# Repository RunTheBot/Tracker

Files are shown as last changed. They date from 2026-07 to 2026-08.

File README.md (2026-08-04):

# Mesh Tracker
A Mesh Tracker based on Meshtastic, in the form of a compass!

Assembly 1



## Features
- LCD For graphics
- Battery and Built-In Charger
- 9 Axis IMU (6 Axis + Magnometer)
- BLE, WiFi, LoRA
- Nearby Pairing

## How it works
Uses LoRa to transmit to the Meshtastic network on a private channel.

## Links
[CAD](https://cad.onshape.com/documents/e3691873ac5a479e26355872/w/654b772ea547b2e6e45daab3/e/722a3034d5cb82f9e90410ab)
[Firmware](https://github.com/runthebot/meshtastic)
[PCB](https://github.com/RunTheBot/Tracker/tree/main/PCB/tracker)
[BOM](https://docs.google.com/spreadsheets/d/1oAZxLPN-XNKiKrUyTvPvqBS-V4H7fdXqoOiTHCyojNU/edit?usp=sharing)

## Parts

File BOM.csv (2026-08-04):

Column 1 | Qty | Price Per | Toral | URL
100mW 0Ω Thick Film Resistor -100ppm/℃~+600ppm/℃ 0402 Chip Resistor - Surface Mount RoHS | 100 |  | 0.45 | https://www.lcsc.com/product-detail/C242160.html
100nF ±10% 50V Ceramic Capacitor X7R 0603 | 50 |  | 1.14 | https://www.lcsc.com/product-detail/C14663.html
10kΩ ±1% 100mW 0603 Thick Film Resistor | 100 |  | 0.38 | https://www.lcsc.com/product-detail/C2906982.html
10uF ±20% 25V Ceramic Capacitor X5R 0603 | 20 |  | 1.66 | https://www.lcsc.com/product-detail/C96446.html
2kΩ ±1% 100mW 0603 Thick Film Resistor | 100 |  | 0.91 | https://www.lcsc.com/product-detail/C22975.html
Connector Receptacle IPEX Male Pin 50Ω Surface Mount | 5 |  | 0.51 | https://www.lcsc.com/product-detail/C88374.html
100mW 4.7kΩ 75V Thick Film Resistor ±100ppm/℃ ±1% 0603 Chip Resistor - Surface Mount RoHS | 100 |  | 0.57 | https://www.lcsc.com/product-detail/C99782.html
4.7uF ±10% 16V Ceramic Capacitor X5R 0603 | 20 |  | 0.67 | https://www.lcsc.com/product-detail/C19666.html
5.1kΩ ±1% 100mW 0603 Thick Film Resistor | 100 |  | 0.27 | https://www.lcsc.com/product-detail/C2907044.html
3.3V Positive Fixed SOT-23-5 Voltage Regulators - Linear, Low Drop Out (LDO) Regulators RoHS | 5 |  | 0.55 | https://www.lcsc.com/product-detail/C23380830.html
Connector Header 2 position 2mm Pitch 2A Right Angle -25℃~+85℃ | 20 |  | 0.79 | https://www.lcsc.com/product-detail/C173752.html
Diode Independent 40V 1A Surface Mount SOD-123FL | 50 |  | 0.73 | https://www.lcsc.com/product-detail/C2909920.html
LGA-14(2.5x3) IMUs (Inertial Measurement Units) RoHS | 3 |  | 13.09 | https://www.lcsc.com/product-detail/C22461202.html
LCC-18(9.7x10.1) RF Receivers RoHS | 3 |  | 32.04 | https://www.lcsc.com/product-detail/C4153167.html
3.75V~6V 1 Lithium Battery 500mA SOT-23-5 Battery Chargers RoHS | 3 |  | 2.96 | https://www.lcsc.com/product-detail/C144308.html
30V 4A Surface Mount SOT-23 | 5 |  | 0.5 | https://www.lcsc.com/product-detail/C15127.html
LGA-16(3x3) Linear, Compass (ICs) RoHS | 3 |  | 4.69 | https://www.lcsc.com/product-detail/C2847467.html
Tactile Switch SPST 2mm 3.9mm x 2.93mm Surface Mount | 10 |  | 0.6 | https://www.lcsc.com/product-detail/C455280.html
USB-C (USB TYPE-C) Receptacle Connector 16 Position Surface Mount, Right Angle | 5 |  | 0.42 | https://www.lcsc.com/product-detail/C2988369.html
Wio-S3 Wireless Module Hand Solder | 3 |  | 23.97 | https://www.seeedstudio.com/Wio-S3-Wireless-Module-p-6832.html
PinSocket_1x07_P2.54mm_Vertical | 1 | 3.15 | 3.15 | https://www.aliexpress.com/item/1005006733621288.html?mp=1
Display | 3 | 6.36 | 19.08 | https://www.aliexpress.com/item/1005008848200231.html
Seeed Shipping |  |  | 17.68
LCSC Shipping |  |  | 12.67

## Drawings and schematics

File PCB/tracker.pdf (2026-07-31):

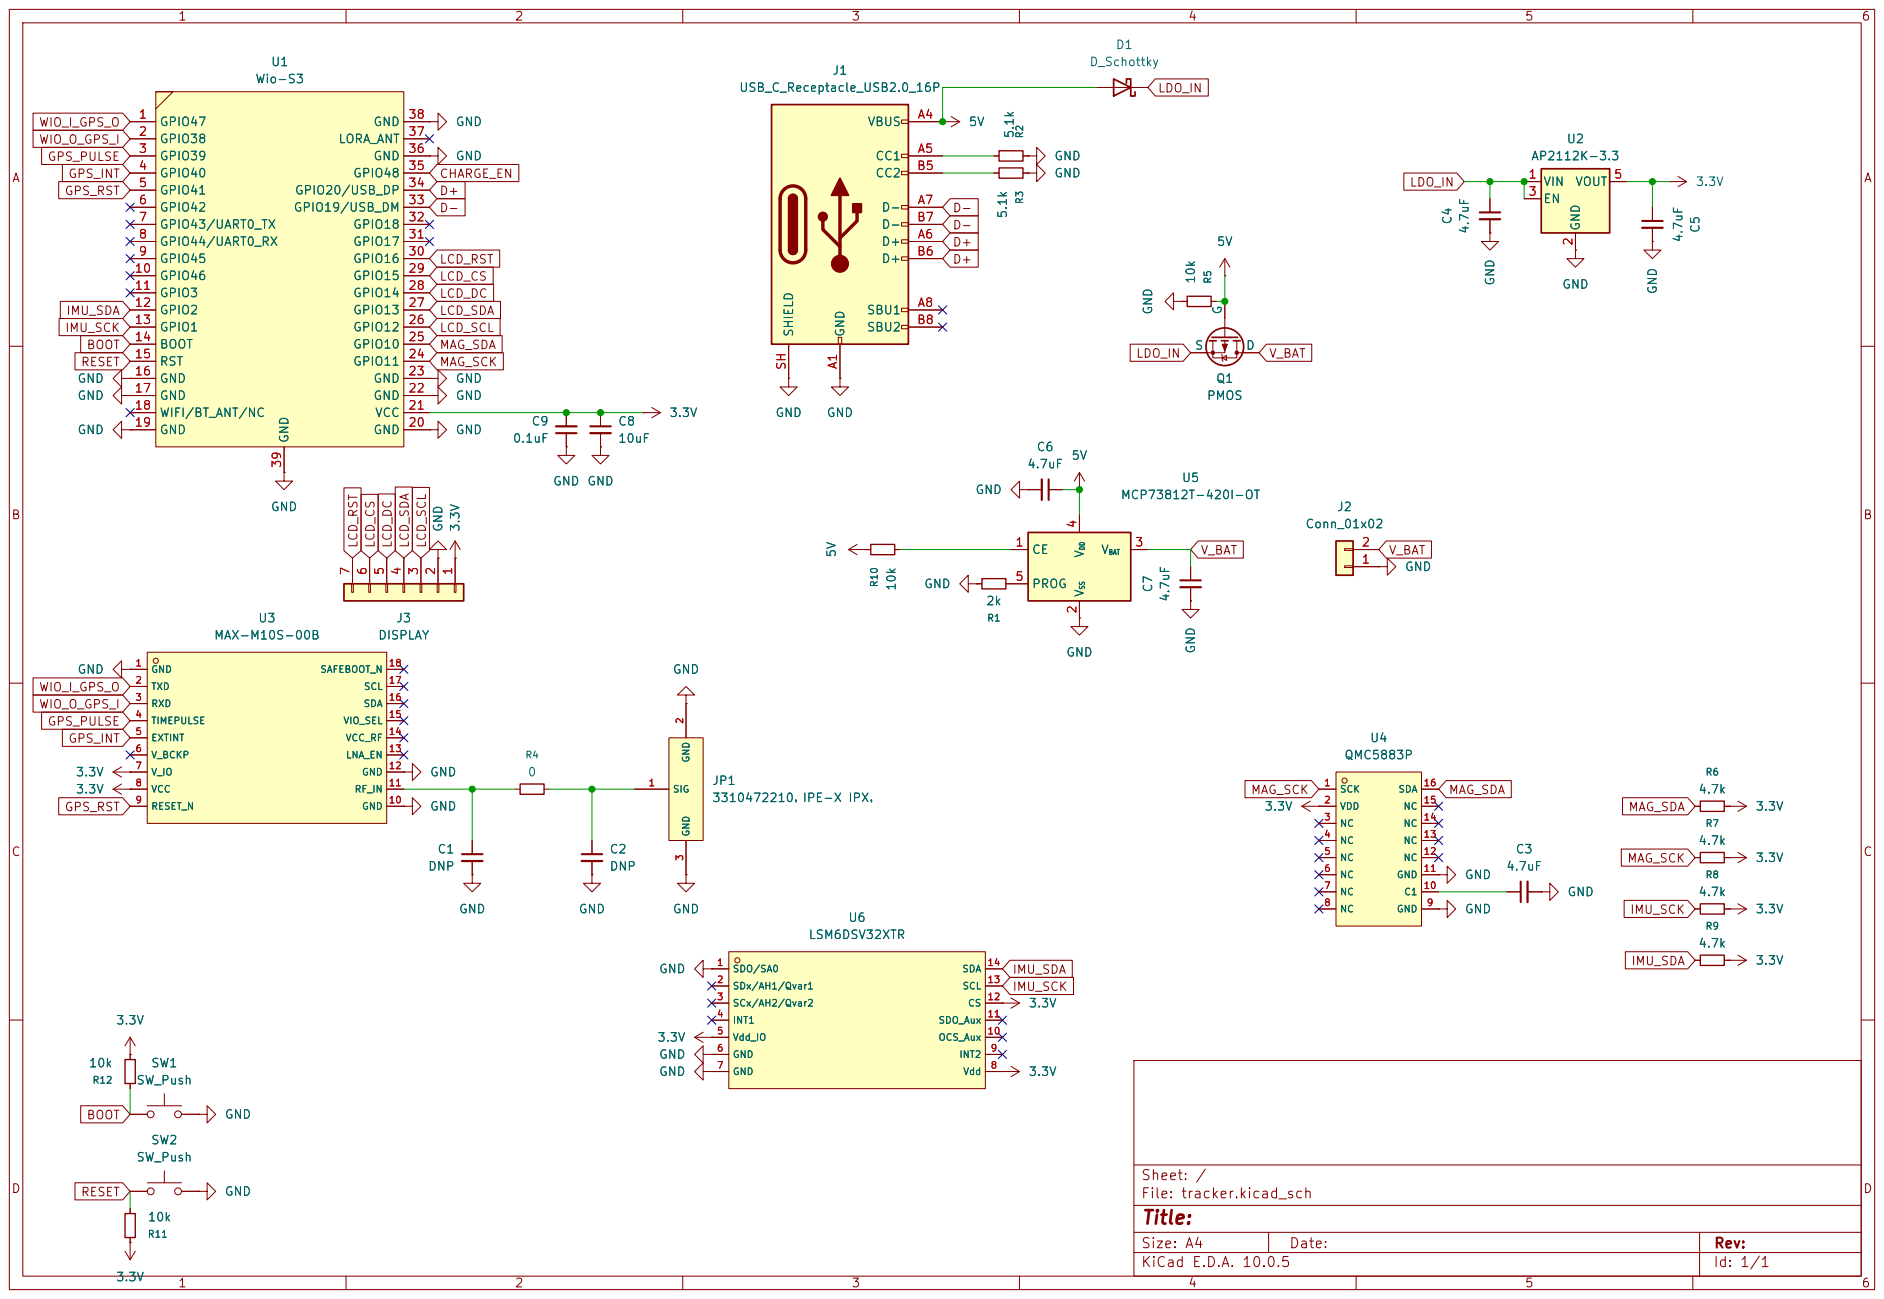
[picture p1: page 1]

VDD 4 PROG 5 GND C7 4.7uF GND GND C5 4.7uF Q1 PMOS D

VDD 4 PROG 5 U5 MCP73812T-420I-OT GND

Size: A4 | Rev:
KiCad E.D.A. 10.0.5 | Id: 1/1

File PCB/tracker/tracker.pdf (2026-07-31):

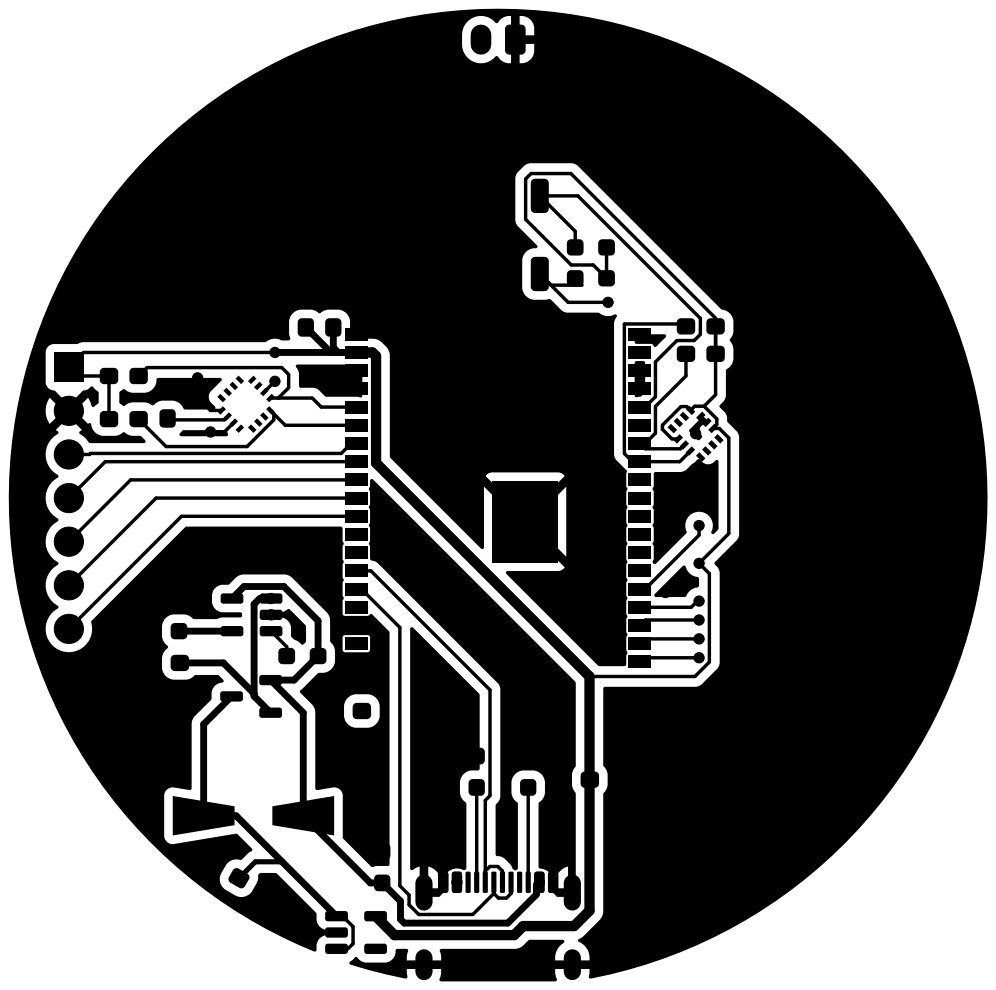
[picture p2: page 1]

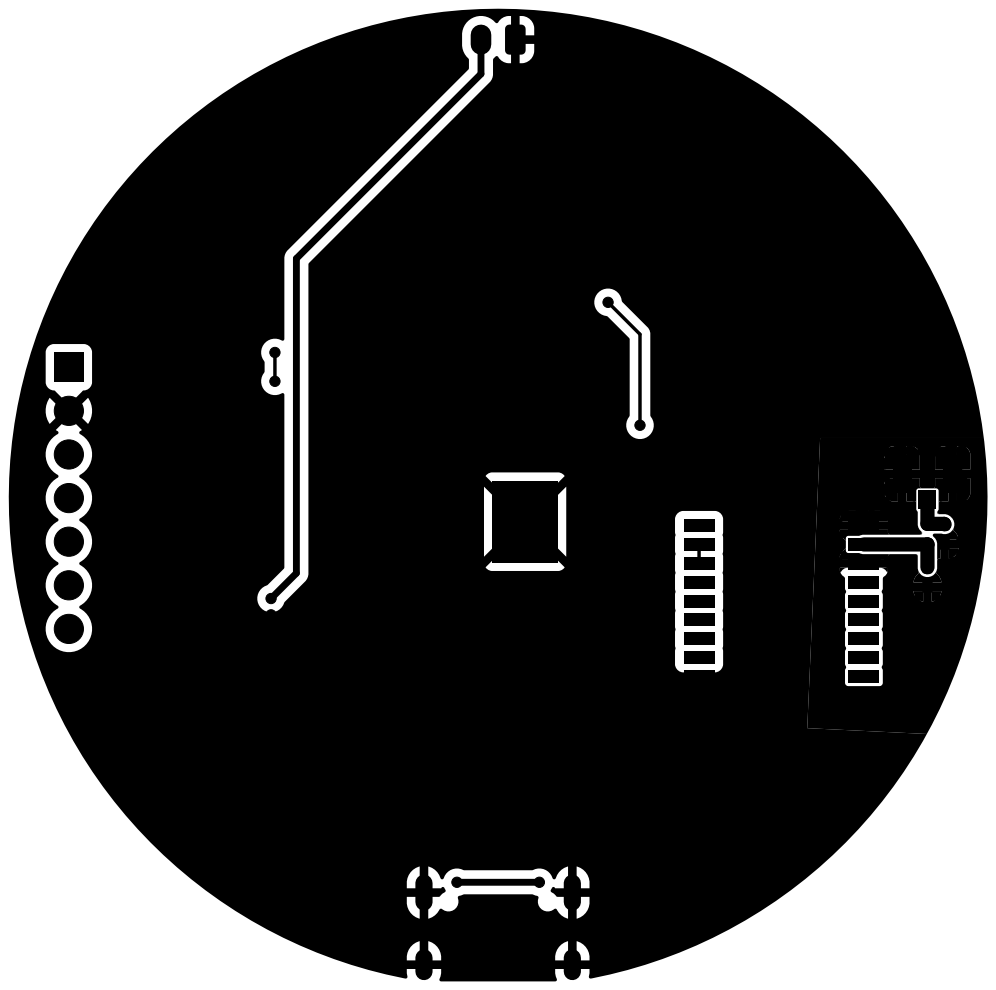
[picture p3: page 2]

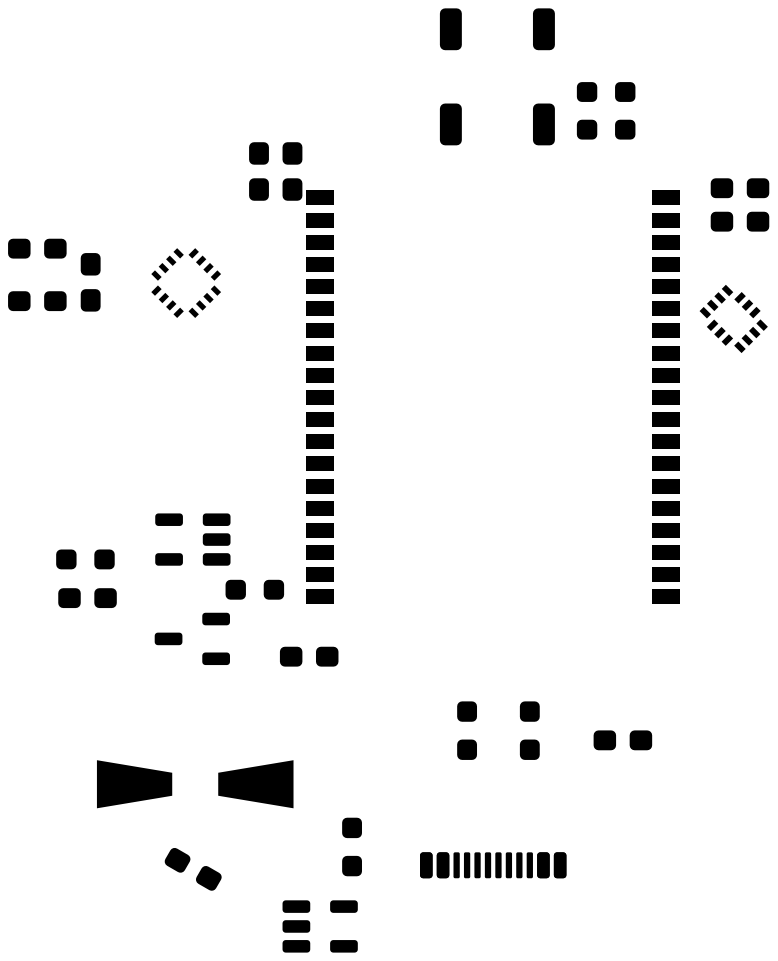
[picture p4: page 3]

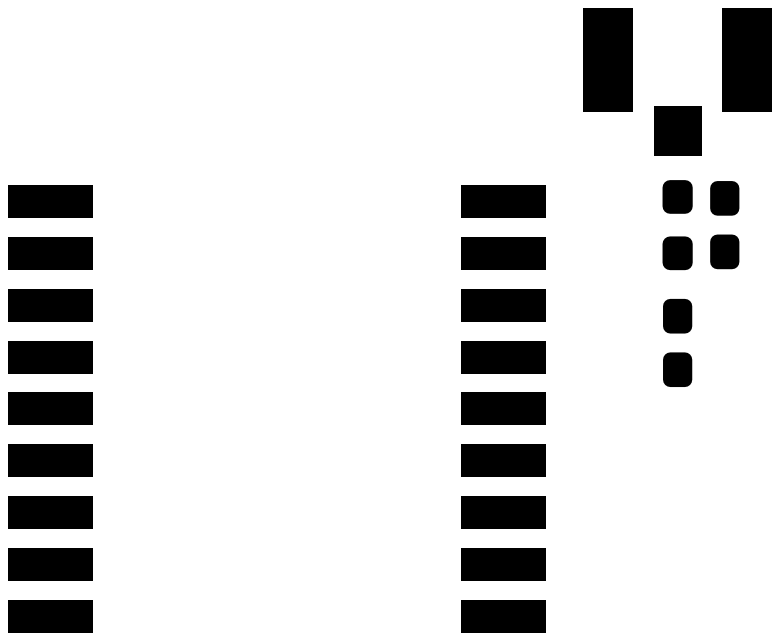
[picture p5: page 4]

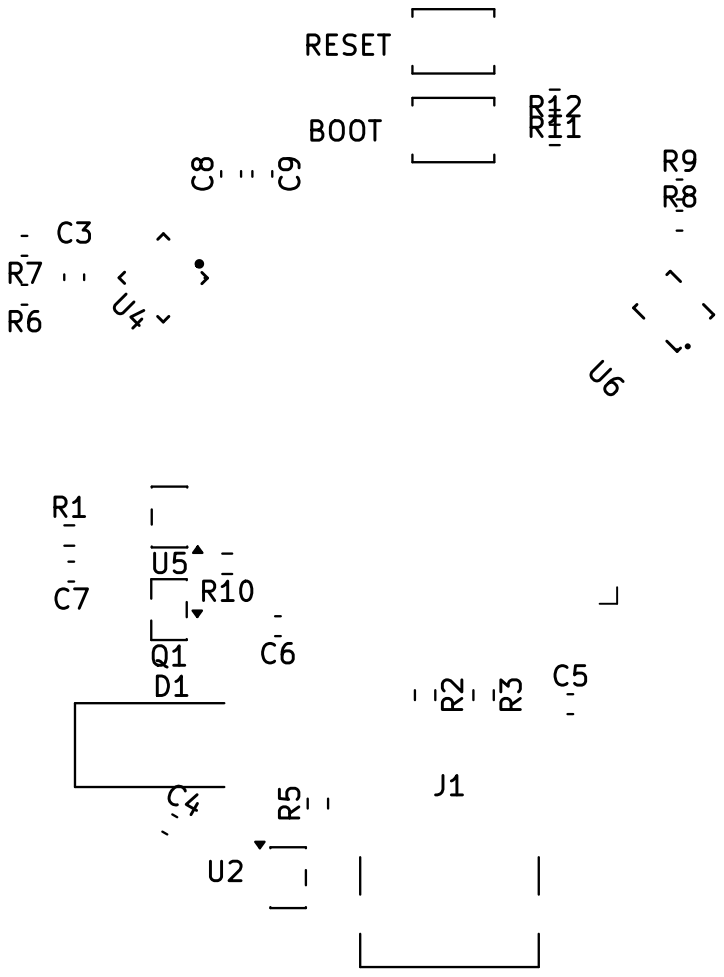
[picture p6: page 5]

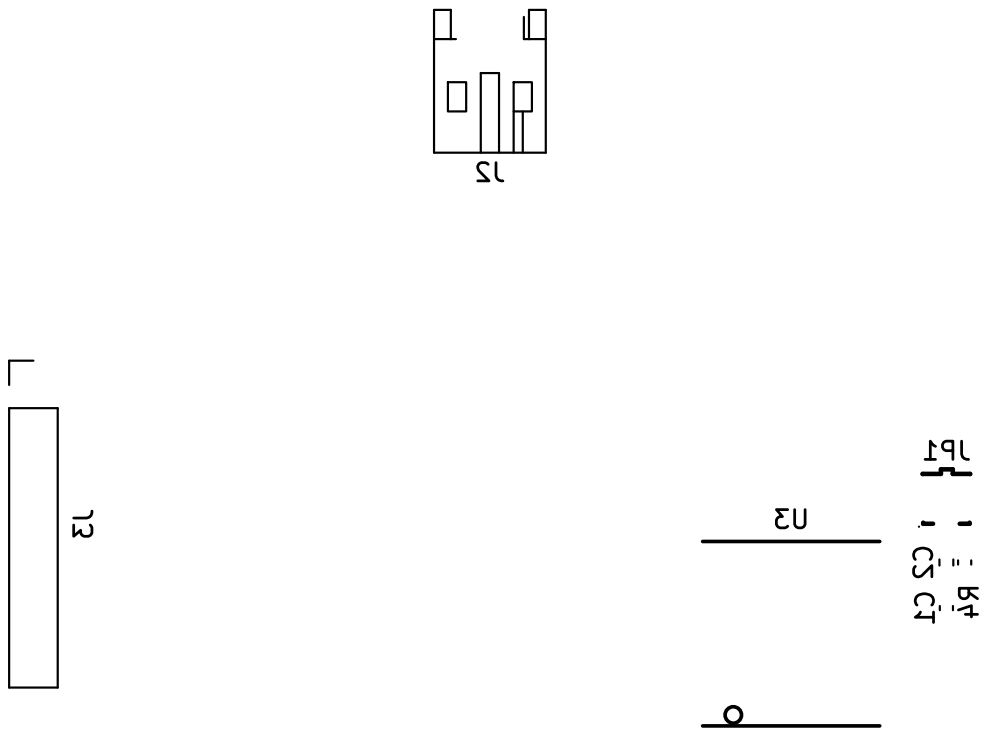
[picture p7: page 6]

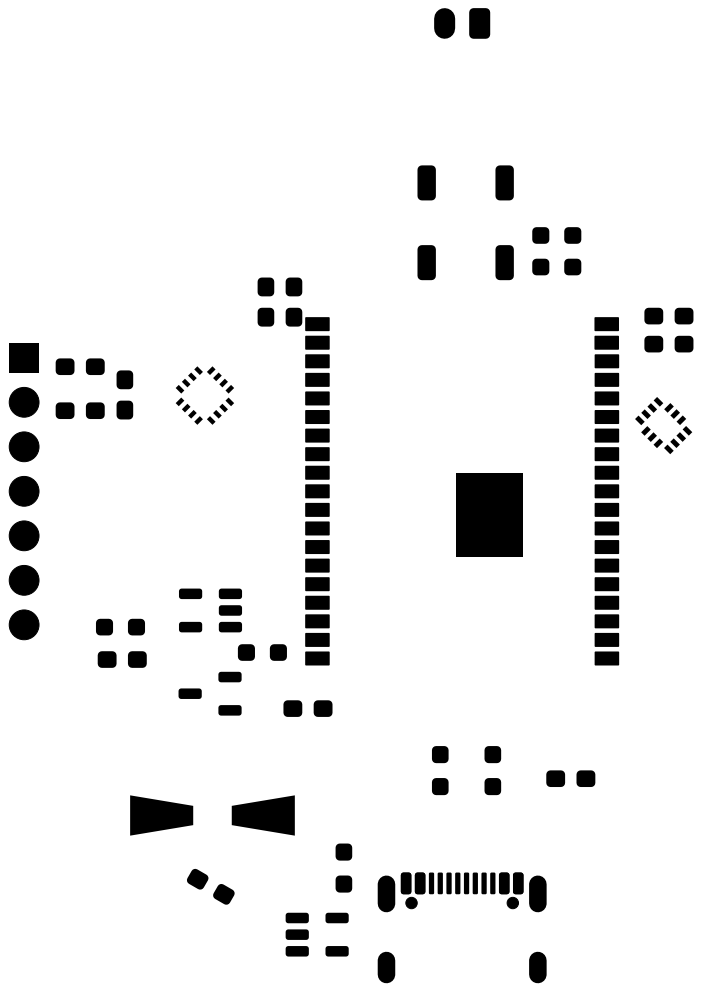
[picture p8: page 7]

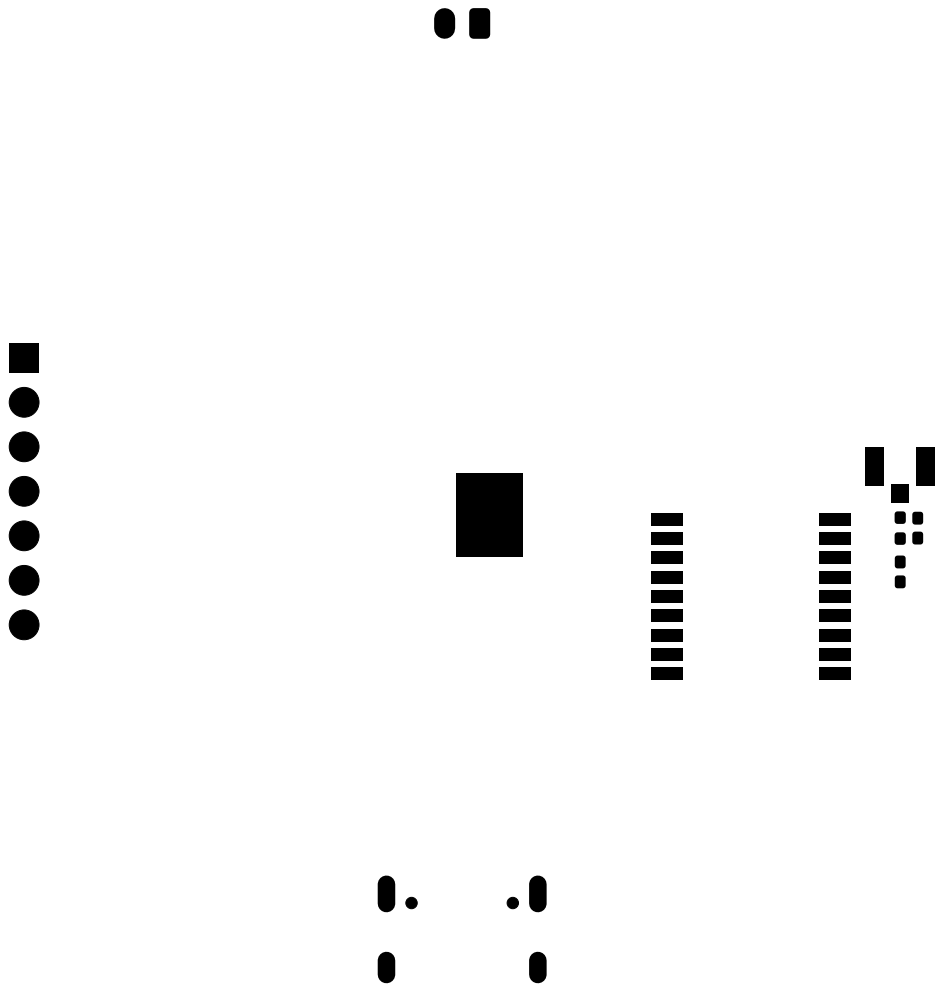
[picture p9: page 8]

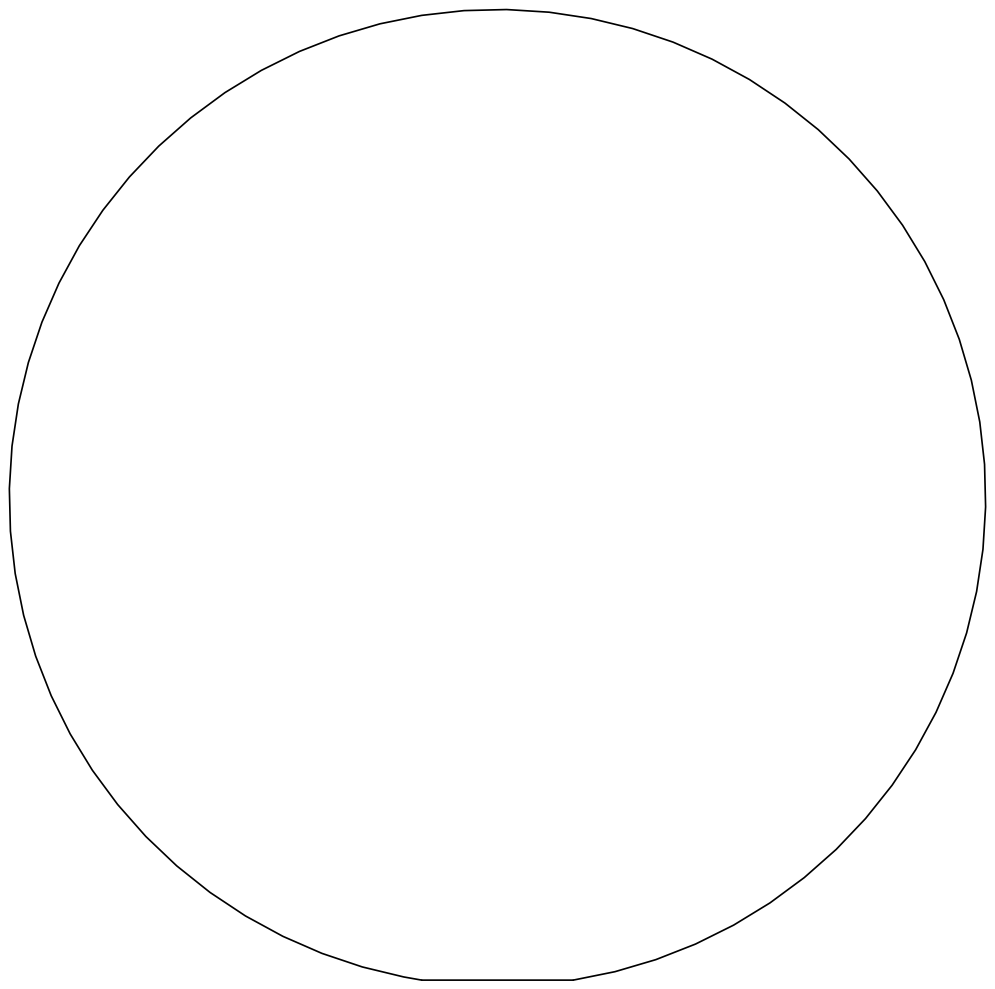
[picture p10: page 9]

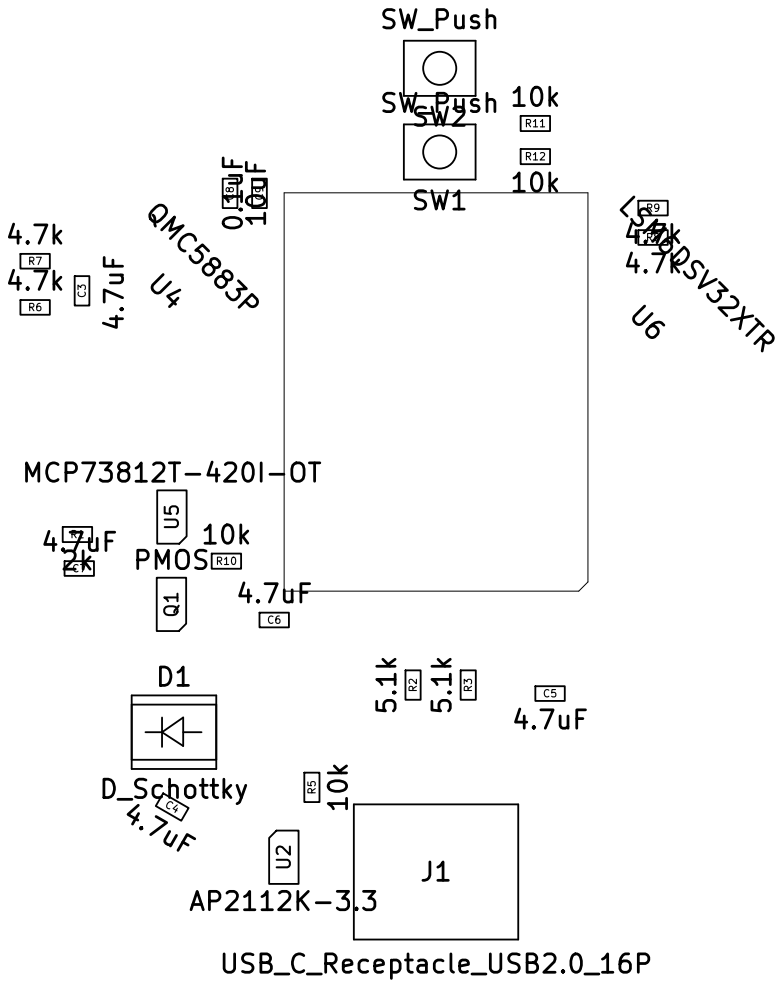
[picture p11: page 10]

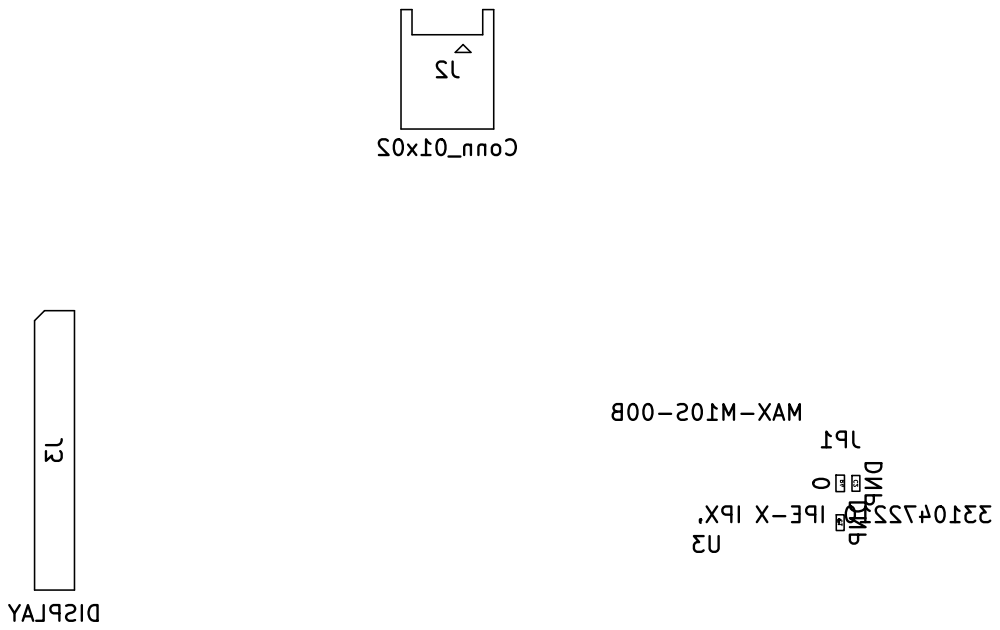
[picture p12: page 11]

SW2

# SW1 Wio-S3

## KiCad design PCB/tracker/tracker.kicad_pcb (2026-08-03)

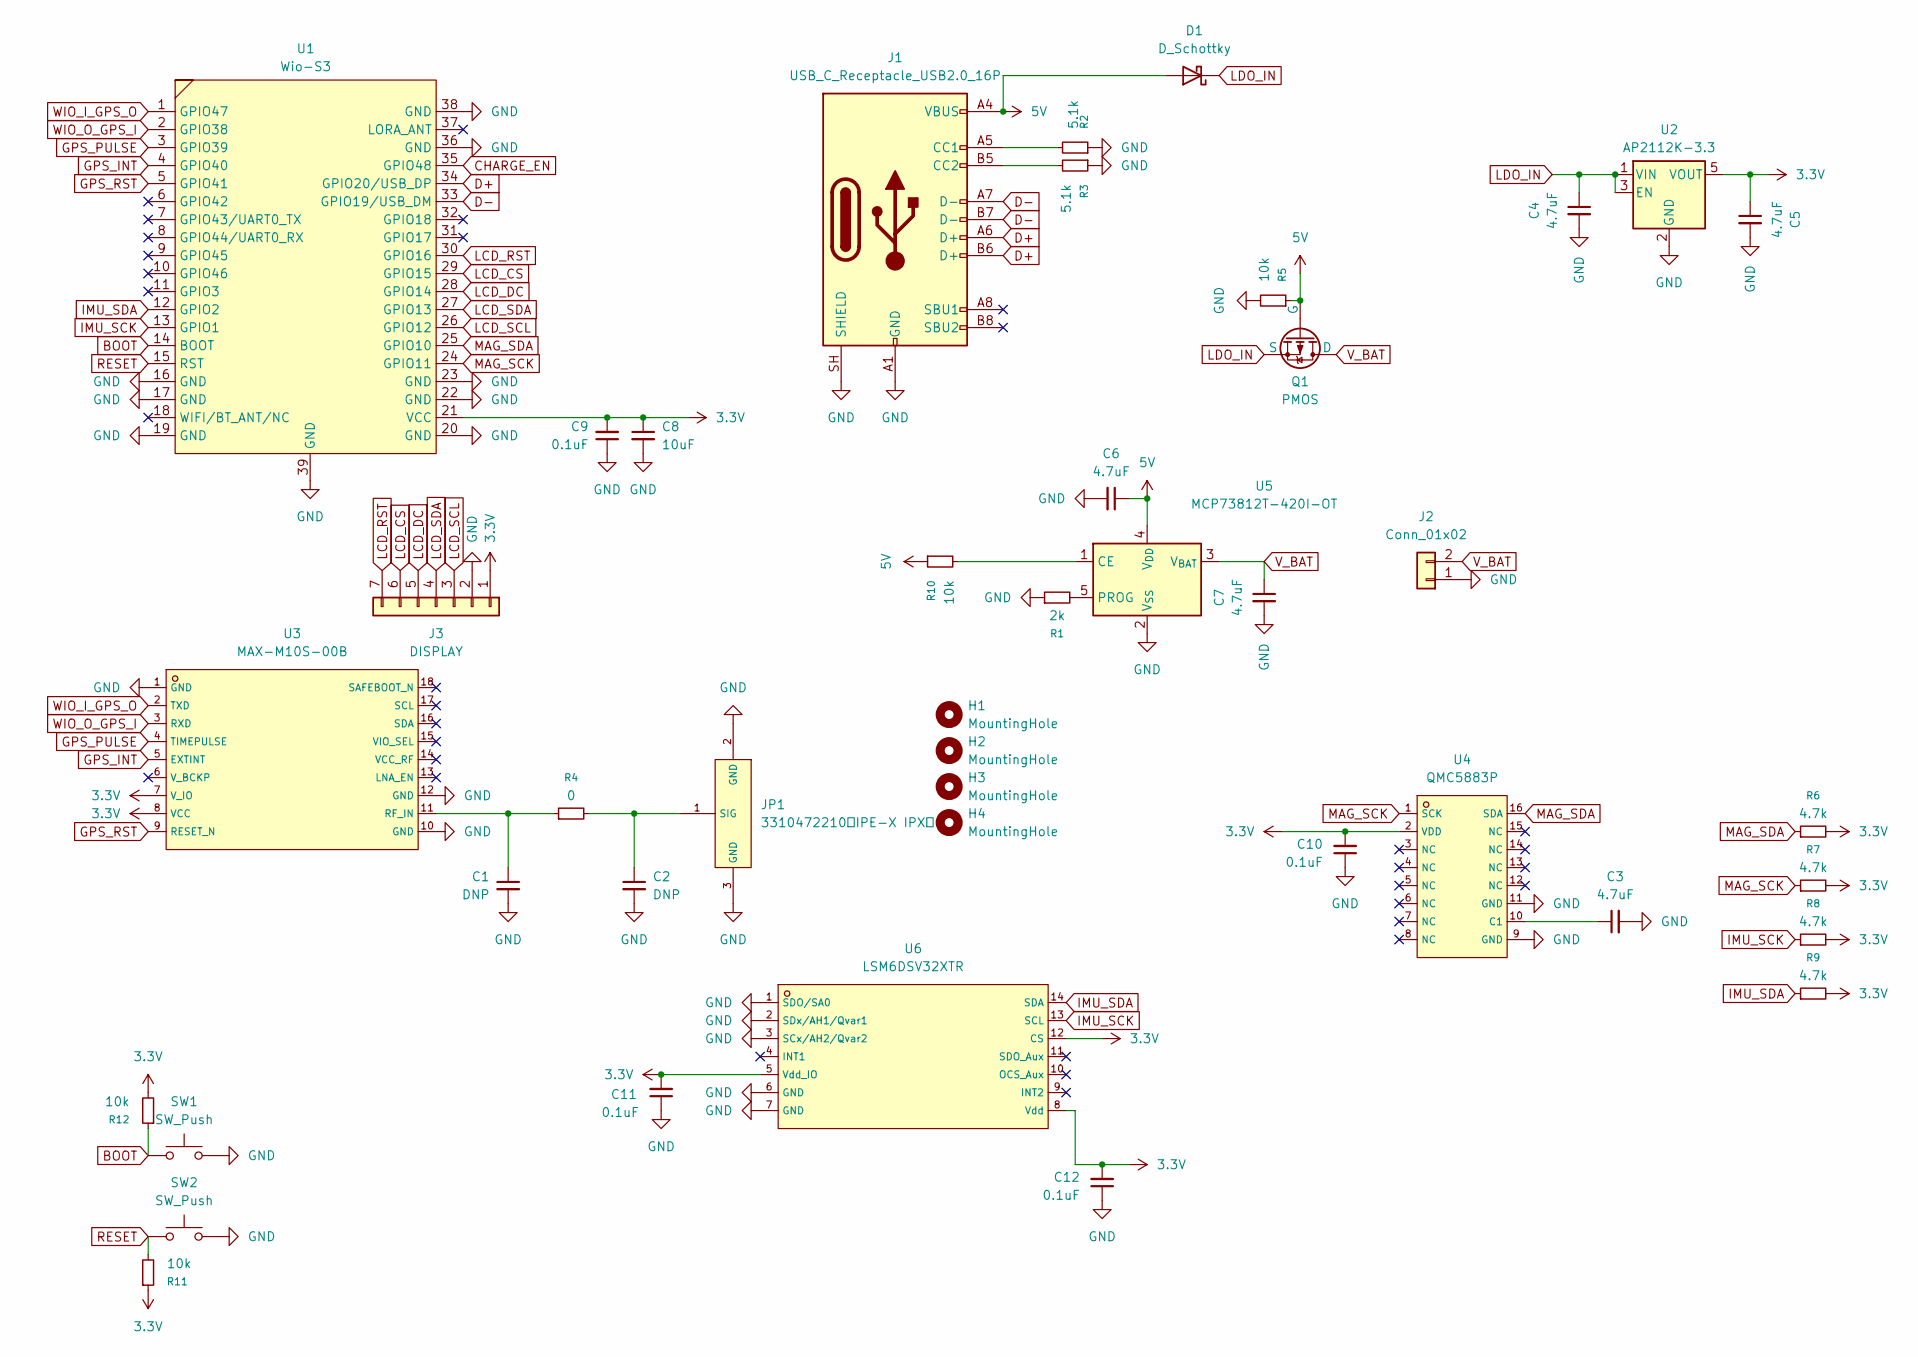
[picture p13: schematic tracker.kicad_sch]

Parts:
C1, C2: DNP; C_0402_1005Metric_Pad0.74x0.62mm_HandSolder
C3, C4, C5, C6, C7: 4.7uF; C_0603_1608Metric_Pad1.08x0.95mm_HandSolder
C8: 10uF; C_0603_1608Metric_Pad1.08x0.95mm_HandSolder
C9, C10, C11, C12: 0.1uF; C_0603_1608Metric_Pad1.08x0.95mm_HandSolder
D1: D_Schottky; D_SOD-123F
H1, H2, H3, H4: MountingHole; MountingHole_3.2mm_M3
J1: USB_C_Receptacle_USB2.0_16P; USB_C_Receptacle_G-Switch_GT-USB-7010ASV
J2: Conn_01x02; JST_PH_S2B-PH-K_1x02_P2.00mm_Horizontal
J3: DISPLAY; PinSocket_1x07_P2.54mm_Vertical
JP1: 3310472210，IPE-X IPX，; C88374_RF-SMD_FRF05002-JSS103M; LCSC C88374
Q1: PMOS; SOT-23-3
R1: 2k; R_0603_1608Metric_Pad0.98x0.95mm_HandSolder
R2, R3: 5.1k; R_0603_1608Metric_Pad0.98x0.95mm_HandSolder
R4: 0; R_0402_1005Metric_Pad0.72x0.64mm_HandSolder
R5, R10, R11, R12: 10k; R_0603_1608Metric_Pad0.98x0.95mm_HandSolder
R6, R7, R8, R9: 4.7k; R_0603_1608Metric_Pad0.98x0.95mm_HandSolder
SW1, SW2: SW_Push; SW_SPST_TS-1088-xR020
U1: Wio-S3; Wio-S3 Wireless Module Hand Solder
U2: AP2112K-3.3; SOT-23-5
U3: MAX-M10S-00B; C4153167_SMD-18_L10_1-W9_7-P1_10-TL_SKG09F; LCSC C4153167
U4: QMC5883P; C2847467_LGA-16_L3_0-W3_0-P0_50-BL_SQ; LCSC C2847467
U5: MCP73812T-420I-OT; SOT-23-5
U6: LSM6DSV32XTR; C22461202_LGA-14L_L3_0-W2_5-P0_50-TL; LCSC C22461202

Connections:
3.3V: C5.1, C8.1, C9.2, C10.2, C11.2, C12.2, J3.1, R6.2, R7.2, R8.2, R9.2, R11.1, R12.2, U1.21 (VCC), U2.5 (VOUT), U3.7 (V_IO), U3.8 (VCC), U4.2 (VDD), U6.5 (Vdd_IO), U6.8 (Vdd), U6.12 (CS)
5V: C6.1, D1.2 (A), J1.A4 (VBUS), J1.A9 (VBUS), J1.B4 (VBUS), J1.B9 (VBUS), Q1.2 (G), R5.1, R10.1, U5.4 (V_{DD})
BOOT: R12.1, SW1.1, U1.14 (BOOT)
CHARGE_EN: U1.35 (GPIO48)
D+: J1.A6 (D+), J1.B6 (D+), U1.34 (GPIO20/USB_DP)
D-: J1.A7 (D-), J1.B7 (D-), U1.33 (GPIO19/USB_DM)
GND: C1.2, C2.2, C3.2, C4.2, C5.2, C6.2, C7.2, C8.2, C9.1, C10.1, C11.1, C12.1, J1.A1 (GND), J1.A12 (GND), J1.B1 (GND), J1.B12 (GND), J1.SH (SHIELD), J2.1, J3.2, JP1.2 (GND), JP1.3 (GND), R1.1, R2.1, R3.1, R5.2, SW1.2, SW2.2, U1.16 (GND), U1.17 (GND), U1.19 (GND), U1.20 (GND), U1.22 (GND), U1.23 (GND), U1.36 (GND), U1.38 (GND), U1.39 (GND), U2.2 (GND), U3.1 (GND), U3.10 (GND), U3.12 (GND), U4.9 (GND), U4.11 (GND), U5.2 (V_{SS}), U6.1 (SDO/SA0), U6.2 (SDx/AH1/Qvar1), U6.3 (SCx/AH2/Qvar2), U6.6 (GND), U6.7 (GND)
GPS_INT: U1.4 (GPIO40), U3.5 (EXTINT)
GPS_PULSE: U1.3 (GPIO39), U3.4 (TIMEPULSE)
GPS_RST: U1.5 (GPIO41), U3.9 (RESET_N)
IMU_SCK: R8.1, U1.13 (GPIO1), U6.13 (SCL)
IMU_SDA: R9.1, U1.12 (GPIO2), U6.14 (SDA)
LCD_CS: J3.6, U1.29 (GPIO15)
LCD_DC: J3.5, U1.28 (GPIO14)
LCD_RST: J3.7, U1.30 (GPIO16)
LCD_SCL: J3.3, U1.26 (GPIO12)
LCD_SDA: J3.4, U1.27 (GPIO13)
LDO_IN: C4.1, D1.1 (K), Q1.3 (S), U2.1 (VIN), U2.3 (EN)
MAG_SCK: R7.1, U1.24 (GPIO11), U4.1 (SCK)
MAG_SDA: R6.1, U1.25 (GPIO10), U4.16 (SDA)
unnamed: J1.A5 (CC1), R2.2
unnamed: J1.B5 (CC2), R3.2
unnamed: C2.1, JP1.1 (SIG), R4.2
unnamed: C1.1, R4.1, U3.11 (RF_IN)
unnamed: C3.1, U4.10 (C1)
unnamed: R10.2, U5.1 (CE)
unnamed: R1.2, U5.5 (PROG)
RESET: R11.2, SW2.1, U1.15 (RST)
V_BAT: C7.1, J2.2, Q1.1 (D), U5.3 (V_{BAT})
WIO_I_GPS_O: U1.1 (GPIO47), U3.2 (TXD)
WIO_O_GPS_I: U1.2 (GPIO38), U3.3 (RXD)

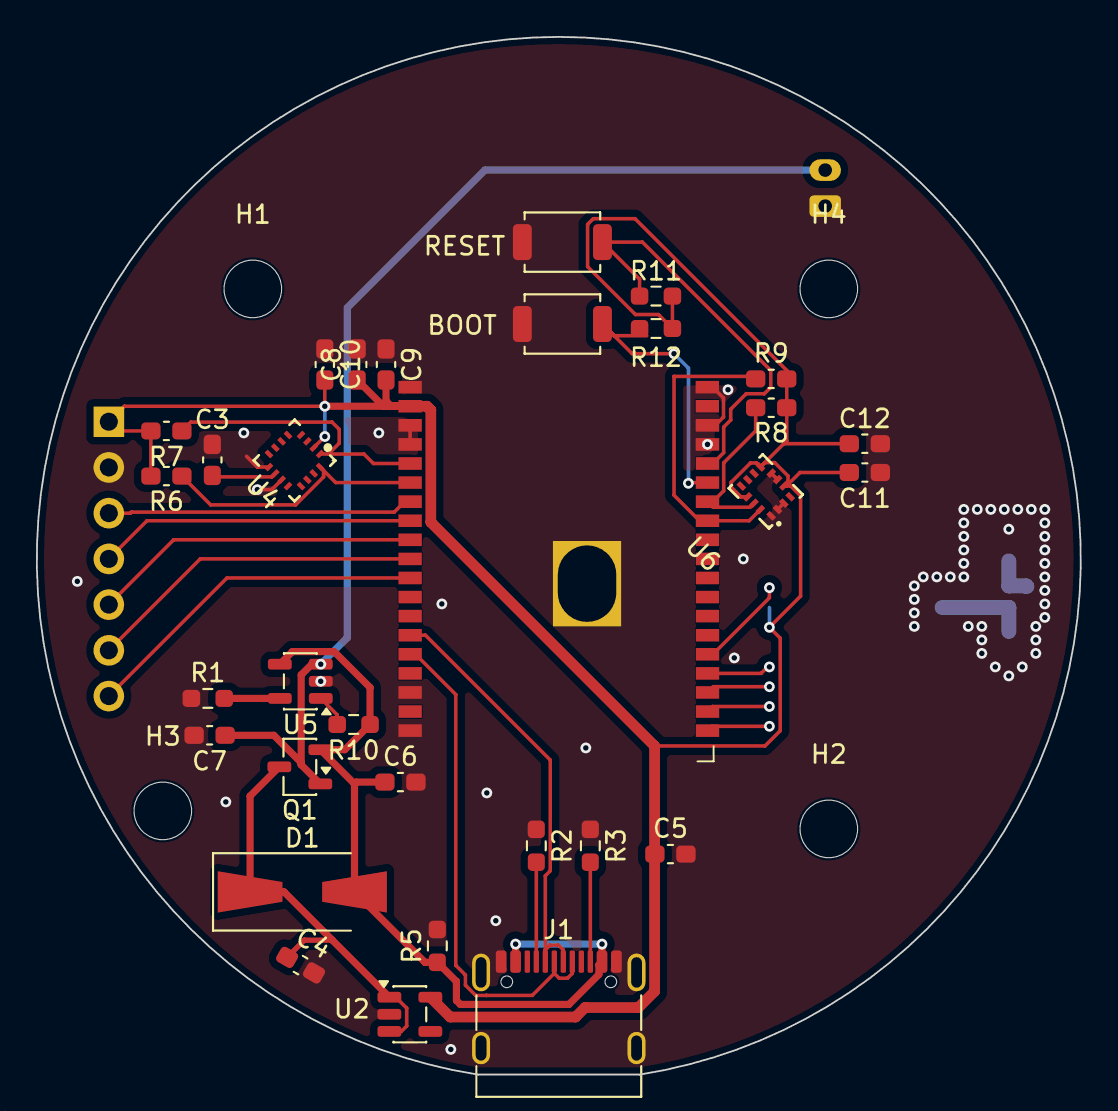
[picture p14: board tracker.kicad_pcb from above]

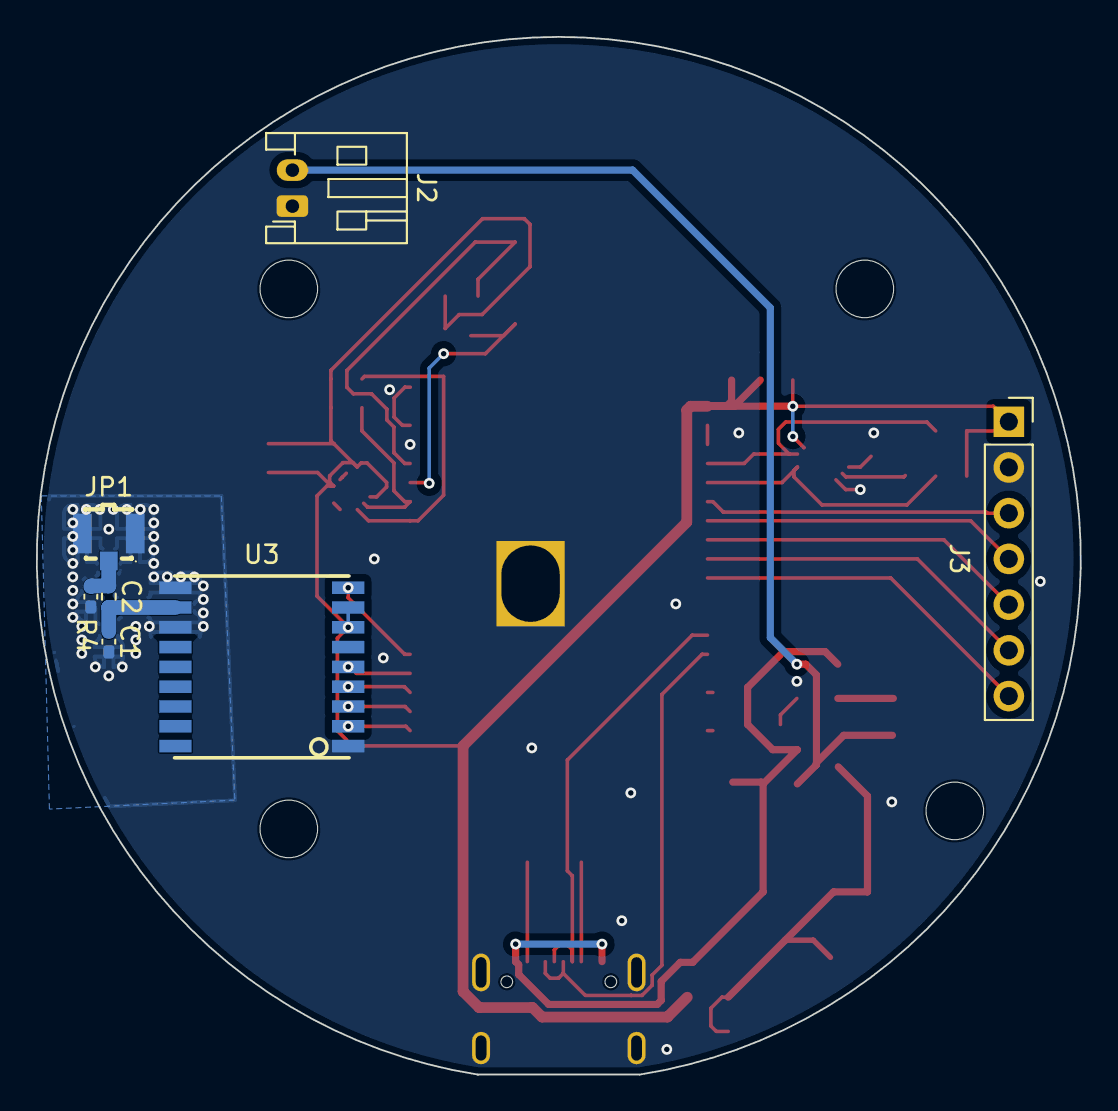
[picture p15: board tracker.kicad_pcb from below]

Board: 2 copper layers, 58.0 x 57.6 mm, 42 parts (7 on the bottom side), 30 nets.

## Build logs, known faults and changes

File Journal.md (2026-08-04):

# Journal
## Jul 24
Hours: 2
Initial Microcontroller research and selection. I chose the Wio-S3 for it's use of external antennas (Less RF to deal with) 

Images...

## Jul 25

Started choosing the ICs that will be used. I chose the GPS chip and a maganometer. 

Did usb stuff and voltage regulation stuff to be able to run the WIO off usb.

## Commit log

2026-07-31 llm review done
    [tracker.kicad_pcb, tracker.kicad_sch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]
2026-08-03 moved shit around
    [tracker.kicad_pcb, tracker.kicad_sch]
2026-08-04 Update PCB and BOM links in README
2026-08-04 Fix CAD link formatting in README
    Removed unnecessary HTML encoding from the CAD link.
